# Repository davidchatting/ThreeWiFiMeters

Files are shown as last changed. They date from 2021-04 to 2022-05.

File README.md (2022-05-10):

# Three WiFi Meters

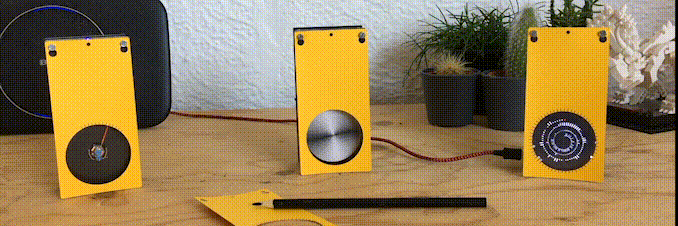
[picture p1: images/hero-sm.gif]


The Three WiFi Meters are three ways of experiencing WiFi networks, each attempts to disclose properties of this near ubiquitous technology. They are built for the [ESP8266](https://en.wikipedia.org/wiki/ESP8266) or [ESP32](https://en.wikipedia.org/wiki/ESP32) using the [Approximate](https://github.com/davidchatting/Approximate) and [YoYoWiFiManager](https://github.com/interactionresearchstudio/YoYoWiFiManager) Arduino libraries.

## [ Signal Strength](SignalStrength)
Measure the signal strength of your router around the house with the [Signal Strength Meter](SignalStrength).

## [ Device Wheel](DeviceWheel)
Watch an individual device's use of the network with the [Device Wheel](DeviceWheel).

## [ Traffic Monitor](TrafficMonitor)
See the traffic on your home WiFi network with the [Traffic Monitor](TrafficMonitor).

## Limitations
The meters work with 2.4GHz WiFi networks, but not 5GHz networks - as neither ESP8266 or ESP32 support this technology.

## A Little History
The Three WiFi Meters are inspired by multiple sources, not least Natalie Jeremijenko's Live Wire (also known as Dangling String) [(Weiser and Brown, 1995)](https://web.archive.org/web/19970624041814/http://www.powergrid.com/1.01/calmtech.html) and the Tangible Media Group's Pinwheels [(Dahley, Wisneski and Ishii, 1998)](https://tangible.media.mit.edu/project/pinwheels/).

## Author
The Three WiFi Meters were created by David Chatting ([@davidchatting](https://twitter.com/davidchatting)) as part of the [A Network of One's Own](http://davidchatting.com/nooo/) project. This code is licensed under the [MIT License](LICENSE.txt).

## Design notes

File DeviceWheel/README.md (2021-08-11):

#  Device Wheel
Watch an individual device's use of the network with this Device Wheel. Once the WiFi is configured by joining the "Home Network Study" network and setting the credentials via the captive portal, bringing an IoT device in proximity of the Device Wheel will cause it to pair and the wheel will spin whenever the is network activity - clockwise for downloads, anti-clockwise for uploads.

## Hardware
* Adafruit HUZZAH32 – ESP32 Feather Board - https://www.adafruit.com/product/3405
* 3800 RPM 1.5mm Diameter Shaft 2V DC Motor for Walkman
* 1.5A Mini Speed Control Dual Channel Motor Driver MX1508
* SPDT Mini Power Switch - https://shop.pimoroni.com/products/spdt-mini-power-switch
* 3mm blue LED
* 1K Ohm resistor
* LiPo Battery Pack 3.7V 500mAh - https://shop.pimoroni.com/products/lipo-battery-pack?variant=20429082055
* Micro USB male to Micro USB female charge + data adapter cable

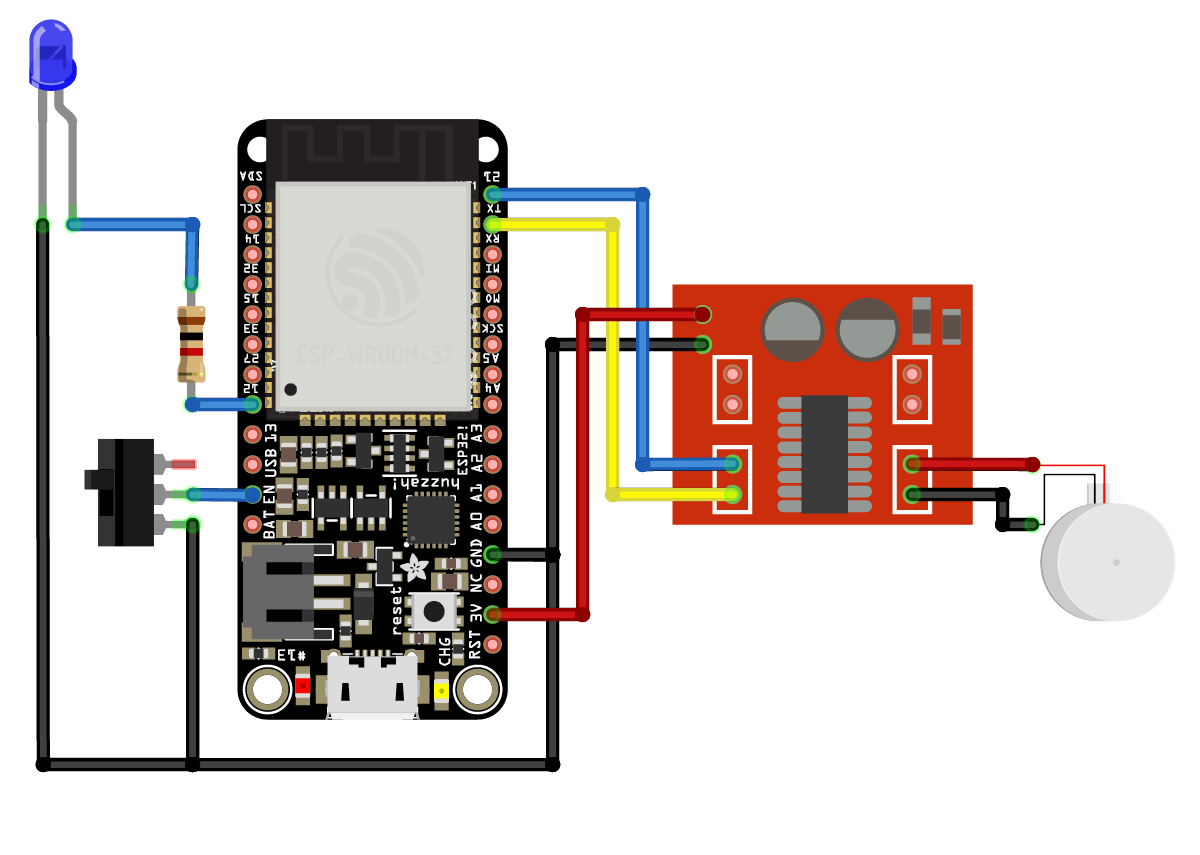
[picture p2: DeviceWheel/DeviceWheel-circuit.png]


The circuit shows an Adafruit HUZZAH32, but the code will compile for any ESP8266 or ESP32 (pin assignments will need to change of course).

## Software
### Arduino
The Arduino core for the ESP8266 or ESP32 must be installed for the Arduino IDE:
* ESP8266 - https://github.com/esp8266/Arduino#installing-with-boards-manager
* ESP32 - https://github.com/espressif/arduino-esp32/blob/master/docs/arduino-ide/boards_manager.md

And the Sketch Data Folder Uploader Tool:
* ESP8266 - https://randomnerdtutorials.com/install-esp8266-filesystem-uploader-arduino-ide/
* ESP32 - https://randomnerdtutorials.com/install-esp32-filesystem-uploader-arduino-ide/

And following Arduino libraries are required:
* Approximate - https://github.com/davidchatting/Approximate/
* YoYoWiFiManager - https://github.com/interactionresearchstudio/YoYoWiFiManager
* ListLib - https://github.com/luisllamasbinaburo/Arduino-List

From the *Tools* menu then select either `Generic ESP822 Module` or `ESP32 Dev Module` and then for the ESP8266 select `4MB (FS:3MB OTA:~512KB)` for *Flash Size* and for the ESP32 select a *Partition Scheme* of `Default 4MB with spiffs (1.2MB APP/1.5MB SPIFFS)` - assuming a *Flash Size* of 4MB. Then upload the associated `data` folder using the uploader tool - also found under the *Tools* menu. The data folder contains the HTML, JavaScript and image files for the captive portal that configures the WiFi. If you don't upload the data folder the portal will say, *Yo Yo Machines default HTML*.

## WiFi Set-up
The WiFi is configured by joining the *Home Network Study* network with the password *blinkblink* and entering the details of your network. If multiple meters are started once they will automaically discover each other and the set-up will shared between them. This is enabled by the [YoYoWiFiManager](https://github.com/interactionresearchstudio/YoYoWiFiManager).

## Author
The Three WiFi Meters were created by David Chatting ([@davidchatting](https://twitter.com/davidchatting)) as part of the [A Network of One's Own](http://davidchatting.com/nooo/) project. This code is licensed under the [MIT License](LICENSE.txt).

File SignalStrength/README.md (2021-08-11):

#  Signal Strength
Measure the signal strength of your router around the house with this Signal Strength Meter. Once the WiFi is configured by joining the "Home Network Study" network and setting the credentials via the captive portal, the analogue meter will reflect the signal strength (RSSI) of the router at that location.

## Hardware
* Adafruit HUZZAH32 – ESP32 Feather Board - https://www.adafruit.com/product/3405
* Eisco 0-30V Single Range Moving Coil Voltmeter - https://www.rapidonline.com/eisco-0-30v-single-range-moving-coil-voltmeter-52-3502 (series resistor needs to be removed)
* SPDT Mini Power Switch - https://shop.pimoroni.com/products/spdt-mini-power-switch
* 3mm blue LED
* 1K Ohm resistor
* LiPo Battery Pack 3.7V 500mAh - https://shop.pimoroni.com/products/lipo-battery-pack?variant=20429082055
* Micro USB male to Micro USB female charge + data adapter cable

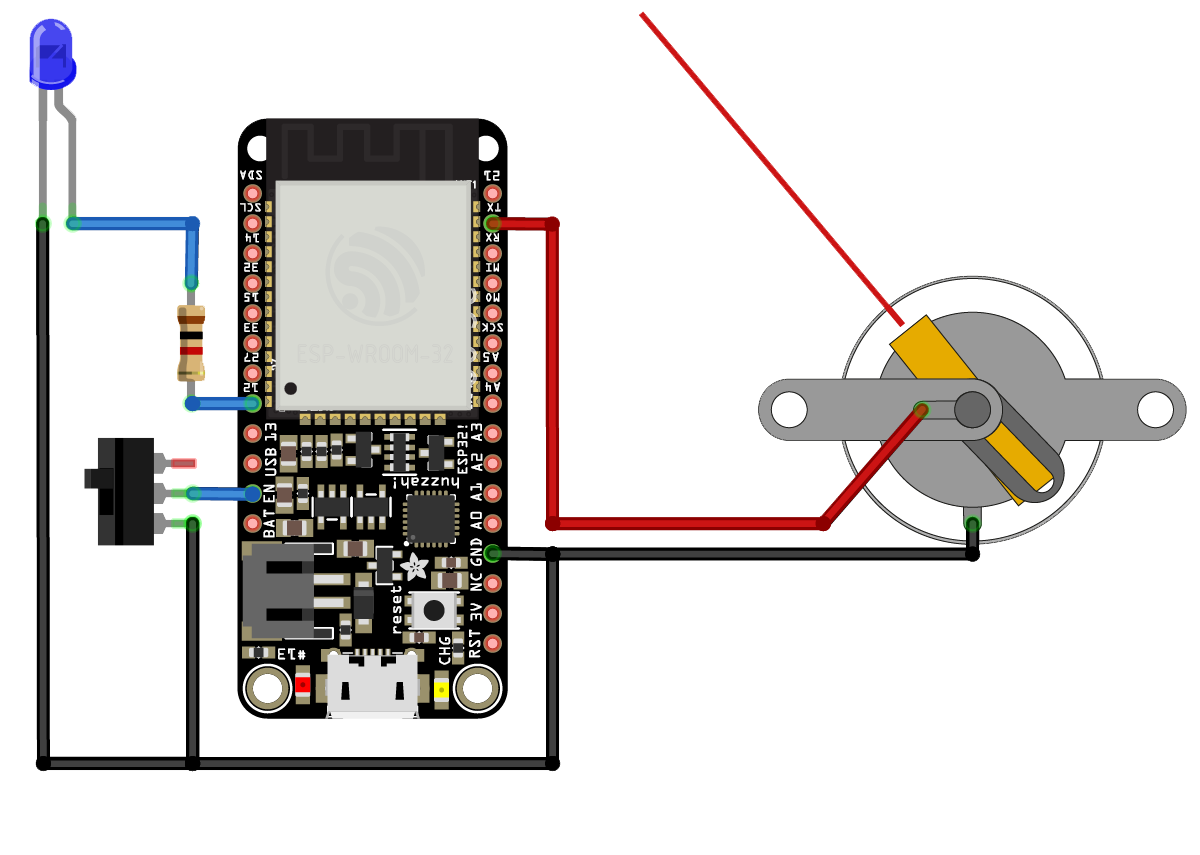
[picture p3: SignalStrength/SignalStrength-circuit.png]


The circuit shows an Adafruit HUZZAH32, but the code will compile for any ESP8266 or ESP32 (pin assignments will need to change of course).

## Software
### Arduino
The Arduino core for the ESP8266 or ESP32 must be installed for the Arduino IDE:
* ESP8266 - https://github.com/esp8266/Arduino#installing-with-boards-manager
* ESP32 - https://github.com/espressif/arduino-esp32/blob/master/docs/arduino-ide/boards_manager.md

And the Sketch Data Folder Uploader Tool:
* ESP8266 - https://randomnerdtutorials.com/install-esp8266-filesystem-uploader-arduino-ide/
* ESP32 - https://randomnerdtutorials.com/install-esp32-filesystem-uploader-arduino-ide/

And following Arduino libraries are required:
* Approximate - https://github.com/davidchatting/Approximate/
* YoYoWiFiManager - https://github.com/interactionresearchstudio/YoYoWiFiManager
* ListLib - https://github.com/luisllamasbinaburo/Arduino-List

From the *Tools* menu then select either `Generic ESP822 Module` or `ESP32 Dev Module` and then for the ESP8266 select `4MB (FS:3MB OTA:~512KB)` for *Flash Size* and for the ESP32 select a *Partition Scheme* of `Default 4MB with spiffs (1.2MB APP/1.5MB SPIFFS)` - assuming a *Flash Size* of 4MB. Then upload the associated `data` folder using the uploader tool - also found under the *Tools* menu. The data folder contains the HTML, JavaScript and image files for the captive portal that configures the WiFi. If you don't upload the data folder the portal will say, *Yo Yo Machines default HTML*.

## WiFi Set-up
The WiFi is configured by joining the *Home Network Study* network with the password *blinkblink* and entering the details of your network. If multiple meters are started once they will automaically discover each other and the set-up will shared between them. This is enabled by the [YoYoWiFiManager](https://github.com/interactionresearchstudio/YoYoWiFiManager).

## Author
The Three WiFi Meters were created by David Chatting ([@davidchatting](https://twitter.com/davidchatting)) as part of the [A Network of One's Own](http://davidchatting.com/nooo/) project. This code is licensed under the [MIT License](LICENSE.txt).

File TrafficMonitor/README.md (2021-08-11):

#  Traffic Monitor
See the traffic on your home WiFi network with this Traffic Monitor. Once the WiFi is configured by joining the "Home Network Study" network and setting the credentials via the captive portal, the last three minutes of network traffic will be displayed. The devices on the network are shown on the periphery of the circle and flash when they are active.

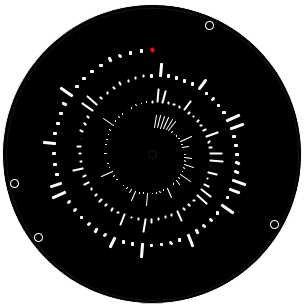
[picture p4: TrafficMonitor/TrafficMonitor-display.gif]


## Hardware
The ESP8266 monitors the network traffic and communicates over a serial connection with the Raspberry Pi, which renders the visualisation.

* Wemos D1 mini ESP8266 
* Raspberry Pi Zero - https://shop.pimoroni.com/products/raspberry-pi-zero-wh-with-pre-soldered-header
* Waveshare 4 inch Raspberry Pi Display - https://www.waveshare.com/wiki/4inch_RPi_LCD_(A)
* 3mm blue LED
* 1K Ohm resistor
* Micro USB male to Micro USB female charge + data adapter cable

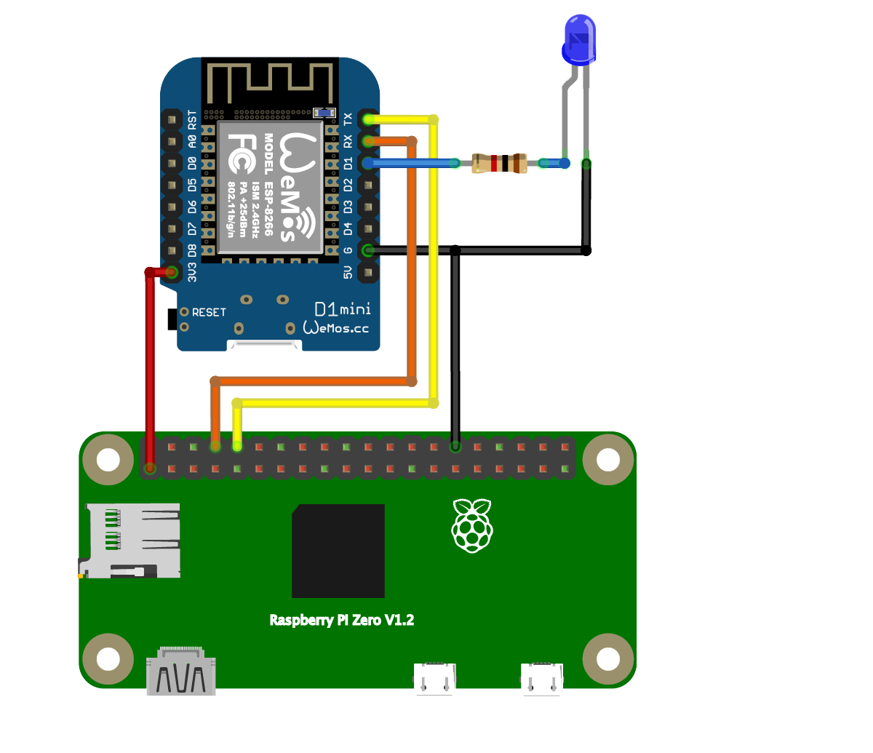
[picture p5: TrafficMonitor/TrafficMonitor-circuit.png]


The circuit shows a Wemos D1 mini ESP8266, but the code will compile for any ESP8266 or ESP32 (pin assignments will need to change of course).

## Software
### Arduino
The Arduino core for the ESP8266 or ESP32 must be installed for the Arduino IDE:
* ESP8266 - https://github.com/esp8266/Arduino#installing-with-boards-manager
* ESP32 - https://github.com/espressif/arduino-esp32/blob/master/docs/arduino-ide/boards_manager.md

And the Sketch Data Folder Uploader Tool:
* ESP8266 - https://randomnerdtutorials.com/install-esp8266-filesystem-uploader-arduino-ide/
* ESP32 - https://randomnerdtutorials.com/install-esp32-filesystem-uploader-arduino-ide/

And following Arduino libraries are required:
* Approximate - https://github.com/davidchatting/Approximate/
* YoYoWiFiManager - https://github.com/interactionresearchstudio/YoYoWiFiManager
* ListLib - https://github.com/luisllamasbinaburo/Arduino-List

From the *Tools* menu then select either `Generic ESP822 Module` or `ESP32 Dev Module` and then for the ESP8266 select `4MB (FS:3MB OTA:~512KB)` for *Flash Size* and for the ESP32 select a *Partition Scheme* of `Default 4MB with spiffs (1.2MB APP/1.5MB SPIFFS)` - assuming a *Flash Size* of 4MB. Then upload the associated `data` folder using the uploader tool - also found under the *Tools* menu. The data folder contains the HTML, JavaScript and image files for the captive portal that configures the WiFi. If you don't upload the data folder the portal will say, *Yo Yo Machines default HTML*.

### Processing
The visulisation code is built for [Processing 3](https://processing.org/) from a desktop this can be easily uploaded to the Raspberry Pi using the [Upload to Pi Tool](https://github.com/gohai/processing-uploadtopi). Alternatively, if the ESP8266 is attached to a desktop machine via USB then it can be run there instead - for platforms other than MacOS that might need some modifcation of ```looksLikeArduino()``` in the sketch.

## WiFi Set-up
The WiFi is configured by joining the *Home Network Study* network with the password *blinkblink* and entering the details of your network. If multiple meters are started once they will automaically discover each other and the set-up will shared between them. This is enabled by the [YoYoWiFiManager](https://github.com/interactionresearchstudio/YoYoWiFiManager).

## Author
The Three WiFi Meters were created by David Chatting ([@davidchatting](https://twitter.com/davidchatting)) as part of the [A Network of One's Own](http://davidchatting.com/nooo/) project. This code is licensed under the [MIT License](LICENSE.txt).

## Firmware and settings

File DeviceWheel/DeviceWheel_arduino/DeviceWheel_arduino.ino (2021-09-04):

/*
    Three WiFi Meters - Device Wheel
    -
    David Chatting - github.com/davidchatting/ThreeWiFiMeters
    MIT License - Copyright (c) March 2021
    Documented here > https://github.com/davidchatting/ThreeWiFiMeters#-device-wheel
*/

#include <YoYoWiFiManager.h>
#include <Approximate.h>
#include <YoYoSettings.h>

YoYoWiFiManager wifiManager;
YoYoSettings *settings;

Approximate approx;

#if defined(ESP8266)
  const int ledPin = 2;
#elif defined(ESP32)
  const int ledPin = 14;
#endif

const int motorPinA = SDA;
const int motorPinB = SCL;
#if defined(ESP32)
  const int motorChannelA = 0;
  const int motorChannelB = 1;
#endif

int targetMotorSpeed = 0;
const unsigned int motorUpdateIntervalMs = 250;
long nextMotorUpdateAtMs = 0;

bool newPair = false;

void setup() {
  Serial.begin(115200);

  pinMode(ledPin, OUTPUT);
  digitalWrite(ledPin, LOW);

  pinMode(motorPinA, OUTPUT);
  pinMode(motorPinB, OUTPUT);
  #if defined(ESP32)
    ledcSetup(motorChannelA, 1000, 8);
    ledcSetup(motorChannelB, 1000, 8);
    ledcAttachPin(motorPinA, motorChannelA);
    ledcAttachPin(motorPinB, motorChannelB);
  #endif

  setMotorSpeed(1024);
  delay(25);
  setMotorSpeed(0);

  settings = new YoYoSettings(512); //Settings must be created here in Setup() as contains call to EEPROM.begin() which will otherwise fail
  wifiManager.init(settings, onceConnected, NULL, NULL, false, 80, -1);

//  const char *macAddress = (*settings)["pair"];
//  if(macAddress) setPair(macAddress);

  //Attempt to connect to a WiFi network previously saved in the settings, 
  //if one can not be found start a captive portal called "YoYoMachines", 
  //with a password of "blinkblink" to configure a new one:
  wifiManager.begin("Home Network Study", "blinkblink");
}

void onceConnected() {
  wifiManager.end();
  
  if (approx.init("","")) {
    approx.setProximateDeviceHandler(onProximateDevice, APPROXIMATE_INTIMATE_RSSI, /*lastSeenTimeoutMs*/ 3000);
    approx.setActiveDeviceHandler(onActiveDevice, /*inclusive*/ false);
    approx.begin();
  }
}

void loop() {
  uint8_t wifiStatus = wifiManager.loop();
  approx.loop();

  if(approx.isRunning()) {
    if(!newPair) digitalWrite(ledPin, HIGH);
    else {
      digitalWrite(ledPin, LOW);
      delay(200);
      digitalWrite(ledPin, HIGH);
      newPair = false;
    }
  }
  else {
    switch(wifiManager.currentMode) {
      case YoYoWiFiManager::YY_MODE_PEER_CLIENT:
        digitalWrite(ledPin, blink(1000));
        break;
      default:  //YY_MODE_PEER_SERVER
        digitalWrite(ledPin, blink(500));
        break;
    }
  }

  updateMotorSpeed();
}

bool blink(int periodMs) {
  return(((millis() / periodMs) % 2) == 0);
}

void onProximateDevice(Device *device, Approximate::DeviceEvent event) {
  switch (event) {
    case Approximate::ARRIVE:
      newPair = true;
      char macAdddress[18];
      device -> getMacAddressAs_c_str(macAdddress);
      (*settings)["pair"] = macAdddress;
      settings->save();
      setPair(macAdddress);
      break;
    case Approximate::DEPART:
      break;
  }
}

void setPair(const char *macAddress) {
  Serial.printf("Paired with: %s\n", macAddress);
  approx.setActiveDeviceFilter(macAddress);
}

void onActiveDevice(Device *device, Approximate::DeviceEvent event) {
  int payloadSizeByte = device -> getPayloadSizeBytes();
  if(device -> isDownloading()) payloadSizeByte *= -1;
  
  setTargetMotorSpeed(payloadSizeByte);
}

void updateMotorSpeed() {
  if(millis() > nextMotorUpdateAtMs) {
    setMotorSpeed(targetMotorSpeed);

    targetMotorSpeed = 0;
    nextMotorUpdateAtMs = millis() + motorUpdateIntervalMs;
  }
}

void setTargetMotorSpeed(int v) {
  targetMotorSpeed = constrain(v, -1024, 1024);
}

void setMotorSpeed(int v) {
  v = constrain(v, -1024, 1024);
  
  float valueA = 0;
  float valueB = 0;

  if(v != 0) {
    if(v > 0) {
      valueA = v;
      valueB = 0;
  
      digitalWrite(motorPinA, HIGH);
      digitalWrite(motorPinB, LOW);
    }
    else {
      valueA = 0;
      valueB = abs(v);
  
      digitalWrite(motorPinA, LOW);
      digitalWrite(motorPinB, HIGH);
    }
    delay(25);
  }

  #if defined(ESP32)
    ledcWrite(motorChannelA, valueA);
    ledcWrite(motorChannelB, valueB);
  #else
    analogWrite(motorPinA, valueA);
    analogWrite(motorPinB, valueB);
  #endif
}

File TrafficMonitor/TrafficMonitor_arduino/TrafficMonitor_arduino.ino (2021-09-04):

/*
    Three WiFi Meters - Traffic Monitor
    -
    David Chatting - github.com/davidchatting/ThreeWiFiMeters
    MIT License - Copyright (c) March 2021
    Documented here > https://github.com/davidchatting/ThreeWiFiMeters#-traffic-monitor
*/

#include <YoYoWiFiManager.h>
#include <Approximate.h>
#include <YoYoSettings.h>

YoYoWiFiManager wifiManager;
YoYoSettings *settings;

Approximate approx;

const int ledPin = 16; //DO

List<Device *> activeDevices;
const int maxActiveDevices = 64;
const int minPayloadSizeBytes = 64;
char status[32];

void setup() {
  Serial.begin(115200);

  pinMode(ledPin, OUTPUT);
  digitalWrite(ledPin, LOW);

  settings = new YoYoSettings(512); //Settings must be created here in Setup() as contains call to EEPROM.begin() which will otherwise fail
  wifiManager.init(settings, onceConnected, NULL, NULL, false, 80, -1);

  //Attempt to connect to a WiFi network previously saved in the settings, 
  //if one can not be found start a captive portal called "YoYoMachines", 
  //with a password of "blinkblink" to configure a new one:
  wifiManager.begin("Home Network Study", "blinkblink");
  randomSeed(analogRead(0));
}

void onceConnected() {
  wifiManager.end();
  
  if (approx.init("", "", false, false, false)) {
    approx.setActiveDeviceHandler(onActiveDevice);
    approx.begin();
  }
}

void loop() {
  uint8_t wifiStatus = wifiManager.loop();
  approx.loop();

  if(approx.isRunning()) {
    digitalWrite(ledPin, HIGH);
  }
  else {
    switch(wifiManager.currentMode) {
      case YoYoWiFiManager::YY_MODE_PEER_CLIENT:
        digitalWrite(ledPin, blink(1000));
        break;
      default:  //YY_MODE_PEER_SERVER
        digitalWrite(ledPin, blink(500));
        break;
    }
  }

  if(Serial.available()) {
    serialEvent();
  }
}

bool blink(int periodMs) {
  return(((millis() / periodMs) % 2) == 0);
}

void onActiveDevice(Device *device, Approximate::DeviceEvent event) {
  int n = activeDevices.Count();
  if (n <= maxActiveDevices) {
    if(n == 0 || device -> getPayloadSizeBytes() > minPayloadSizeBytes || random(10) == 0) {
      activeDevices.Add(new Device(device));
    }
  }
}

void serialEvent() {
  while (Serial.available()) {
    if((char)Serial.read() == 'x') {
      wifiManager.getStatusAsString(status);

      if(activeDevices.Count() > 0) {
        char macAddress[18];
 
        while (activeDevices.Count() > 0) {
          Device *activeDevice = activeDevices[0];
          
          Serial.printf("[aprx]\t%s\t%s\t%i\t%i\n", status, activeDevice->getMacAddressAs_c_str(macAddress), activeDevice->getUploadSizeBytes(), activeDevice->getDownloadSizeBytes());
          activeDevices.Remove(0);
          delete activeDevice;
        }
      }
      else {
        Serial.printf("[aprx]\t%s\n", status);
      }
    }
  }
}

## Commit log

2018-06-19 basic stepper example working on NodeMCU
2018-07-12 Access Point allows 3 clients max (allows config of device by phone etc - eg for Google Home)
2018-07-12 driving the stepper directly from the NodeMCU
2018-07-16 arduino stepper experiments
2018-10-26 traceroute implemented with scapy experiments
2018-11-19 Updated MQTT Humidity Sensor for the Wemos and Breadsticks
2019-03-27 nmap-test working properly populates array of devices - also tidy-up
2019-03-27 integrated nmap and traceroute for device id and network testing
2019-05-29 Wheel speed experiments
2019-07-20 working 802.11 frame sniffing with scapy + app framework for trafficmonitor.py
2020-10-24 WiP - basic device and traffic display
2020-11-09 Fix bug with time jumping
    [TrafficMonitor_processing.pde]
2020-11-09 Fix broadcast and OUI identification/filtering
    [TrafficMonitor_processing.pde]
2020-11-18 Tidying-up DeviceWheel folder
2020-11-20 Improved performance and display for Raspberry Pi Zero
2021-02-15 Recognises Raspberry Pi Zero serial port
2021-02-16 Catch exception that was causing crash
    [Observations.pde]
2021-02-16 Was flashing devices too quickly for Raspberry Pi + parse status message
2021-03-09 Instrument now has an external LED
2021-03-31 Changed status LED behaviour + ESP32 compatible analogWrite() alternative
2021-04-10 Fritzing diagrams - WiP
    [DeviceWheel.fzz, SignalStrength.fzz, TrafficMonitor.fzz]
2021-04-10 Filter ESP devices + serialIsConnected
2021-04-10 Arduino code now in _arduino folders
2021-04-19 Gauge now working on ESP32
2021-04-19 Work in Progress
    [SignalStrength.fzz]
2021-04-19 Renamed to DeviceWheel_arduino.ino
2021-04-20 Using pins names defined by Feather (good for ESP8266 and ESP32 versions)
2021-04-23 Putting in place some structure
    [DeviceWheel.fzz, SignalStrength.fzz]
2021-04-26 Renamed Fritzing files
    [DeviceWheel-circuit.fzz, SignalStrength-circuit.fzz, SignalStrength.fzz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]
2021-04-26 Updated Fritzing circuits
    [DeviceWheel-circuit.fzz, SignalStrength.fzz, TrafficMonitor-circuit.fzz]
2021-04-26 + circuit diagrams
2021-04-26 All circuit images the same width (and scale)
2021-04-26 set circuit images widths
2021-04-27 no switch
2021-04-28 Aligned circuit diagrams
2021-05-20 Restructuring of serial code - no longer using serialEvent() - fixed crashing bug when thisDevice.manufacturer is null + reconnection to serial after 10 seconds
    [TrafficMonitor_processing.pde]
2021-05-20 Fixed bug with position allocation - now only allocated if displayed
    [TrafficMonitor_processing.pde]
2021-05-21 new updateTicks() function that maintains a new ticks array, caching results rather than calculating for every draw - will improve performance significantly (especially for Raspberry Pi Zero)
2021-05-23 Slow down frame rate to 12 fps - should further improve performance on Raspberry Pi Zero
2021-05-23 Filter small payload sizes - less than minPayloadSizeBytes
2021-05-23 Console line for individual devices now flash on activity like the device circles
2021-05-26 Use of new Approximate init() to get packets without any filtering
2021-05-26 Display traffic even if the device can't be identified
2021-07-07 +acceptPacket() - used to filter group and broadcast addresses
2021-07-20 Simplified console text + does show unidentified devices + improved acceptPacket() pattern matching + allow comments in nmap-mac-prefixes file
2021-07-21 Extract currentStatus + display traffic for multicast/broadcast/bridge addresses (they alias real devices) but don't display them on the list or as devices on the dial
2021-07-21 Approximate Library now internally filters its own MAC address out of the results
2021-07-21 Should only display device on the console if active in the last minute
2021-09-04 updated LED behaviour + update Approximate init() call
2021-09-04 updated LED behaviour + change gauge sensitivity
2021-09-04 updated LED behaviour
